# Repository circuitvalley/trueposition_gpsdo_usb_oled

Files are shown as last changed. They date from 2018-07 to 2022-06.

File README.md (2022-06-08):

PIC18F25K50 TruePosition GPSDO , USB serial, OLED.
===
/*******************************************************************************
    
    Author:  Gaurav Singh
    
    website: www.circuitvalley.com 
    
    Created on July 12, 2018
    
    PIC18F25K50 TruePosition GPSDO Controller Firmware with USB and OLED Display.

    PIC18F25K50 TruePosition GPSDO Controller Firmware with USB and OLED Display is free software: 
    you can redistribute it and/or modify it under the terms of the GNU General Public License as published by
    the Free Software Foundation, either version 3 of the License, or (at your option) any later version.

    PIC18F25K50 TruePosition GPSDO Controller Firmware with USB and OLED Display is distributed in 
    the hope that it will be useful, but WITHOUT ANY WARRANTY; 
    without even the implied warranty of MERCHANTABILITY or FITNESS FOR A PARTICULAR PURPOSE.  
    See the GNU General Public License for more details.

    You should have received a copy of the GNU General Public License
    along with PIC18F25K50 TruePosition GPSDO Controller Firmware with USB and OLED Display. 
    If not, see <http://www.gnu.org/licenses/>.

*******************************************************************************/
#Distribution Board Blog post
https://www.circuitvalley.com/2018/07/diy-isolated-10mhz-distribution-amp-gpsdo-rubidium-tcxo-reference.html

#Trueposition GPSDO
https://www.circuitvalley.com/2018/07/gpsdo-10mhz-standard-reference-clock-distribution-trueposition-gps-tcxo-ocxo.html

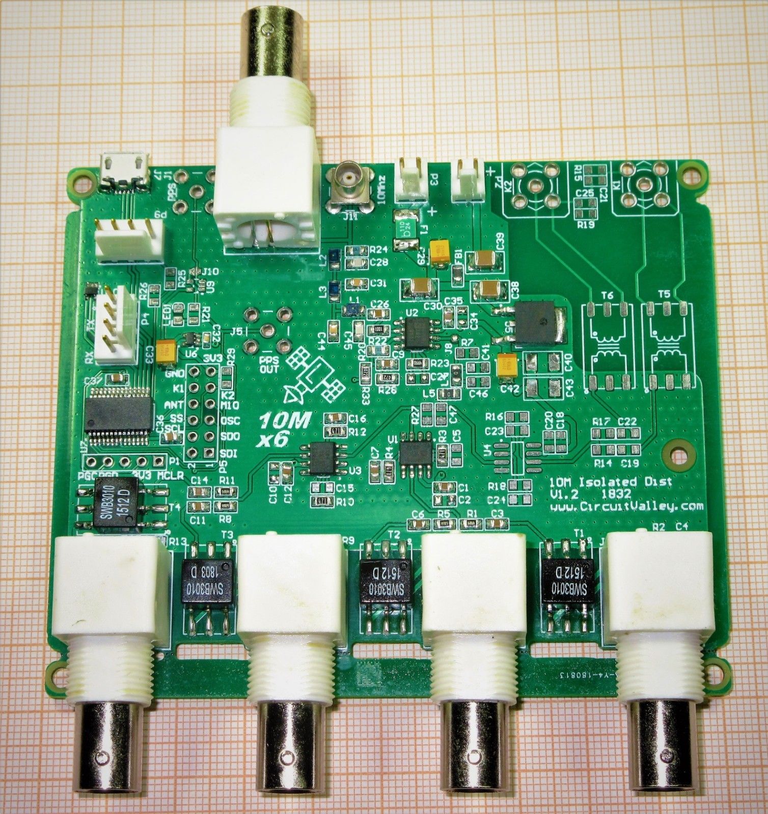
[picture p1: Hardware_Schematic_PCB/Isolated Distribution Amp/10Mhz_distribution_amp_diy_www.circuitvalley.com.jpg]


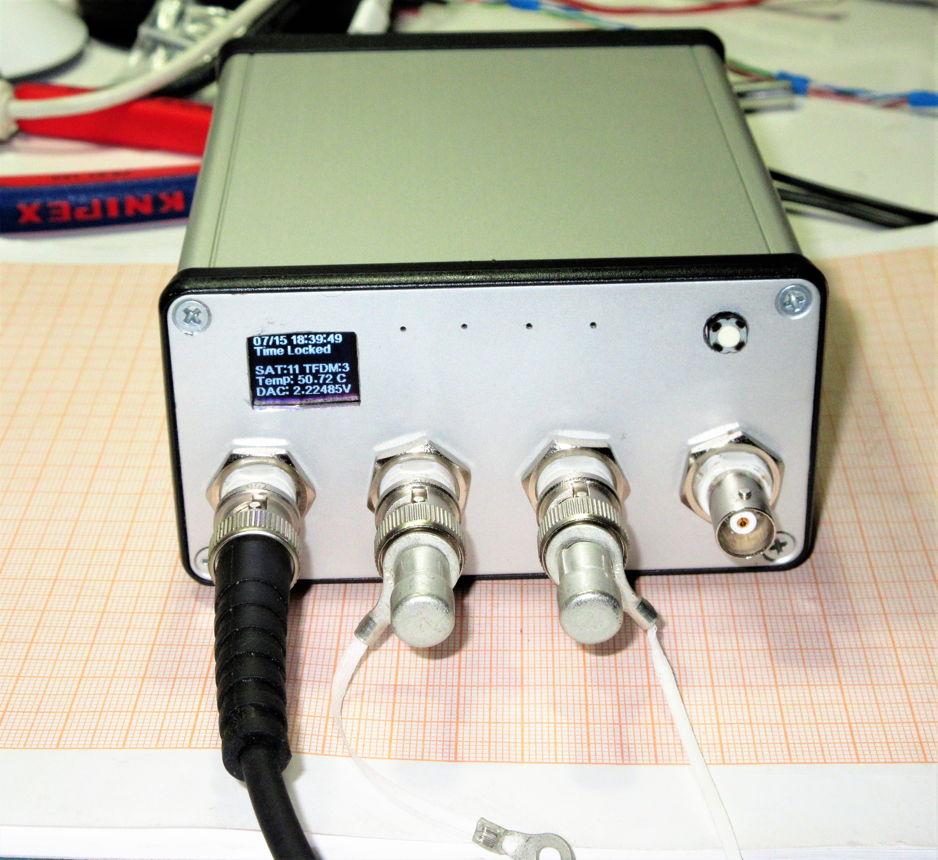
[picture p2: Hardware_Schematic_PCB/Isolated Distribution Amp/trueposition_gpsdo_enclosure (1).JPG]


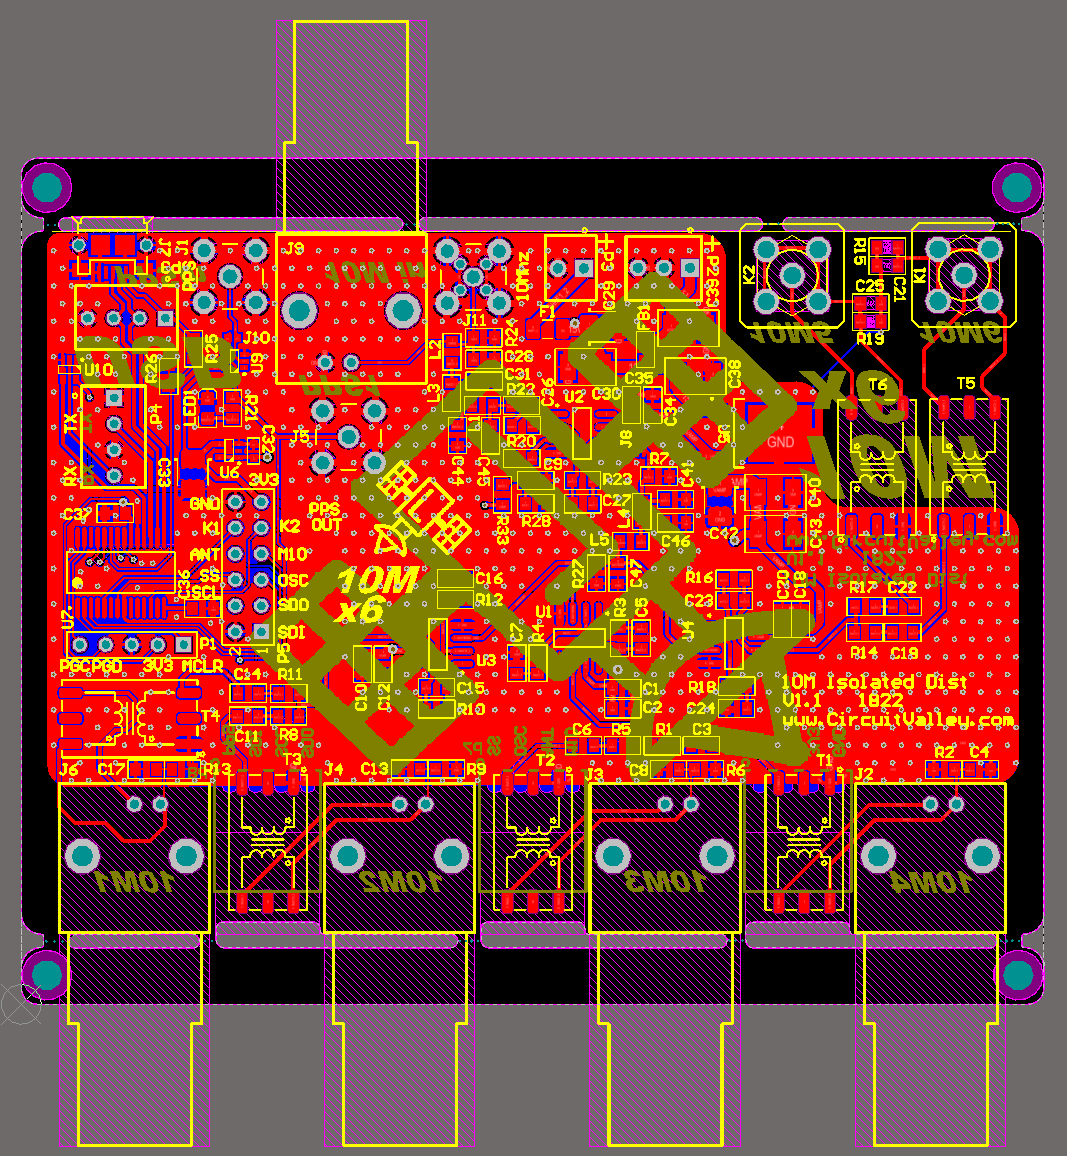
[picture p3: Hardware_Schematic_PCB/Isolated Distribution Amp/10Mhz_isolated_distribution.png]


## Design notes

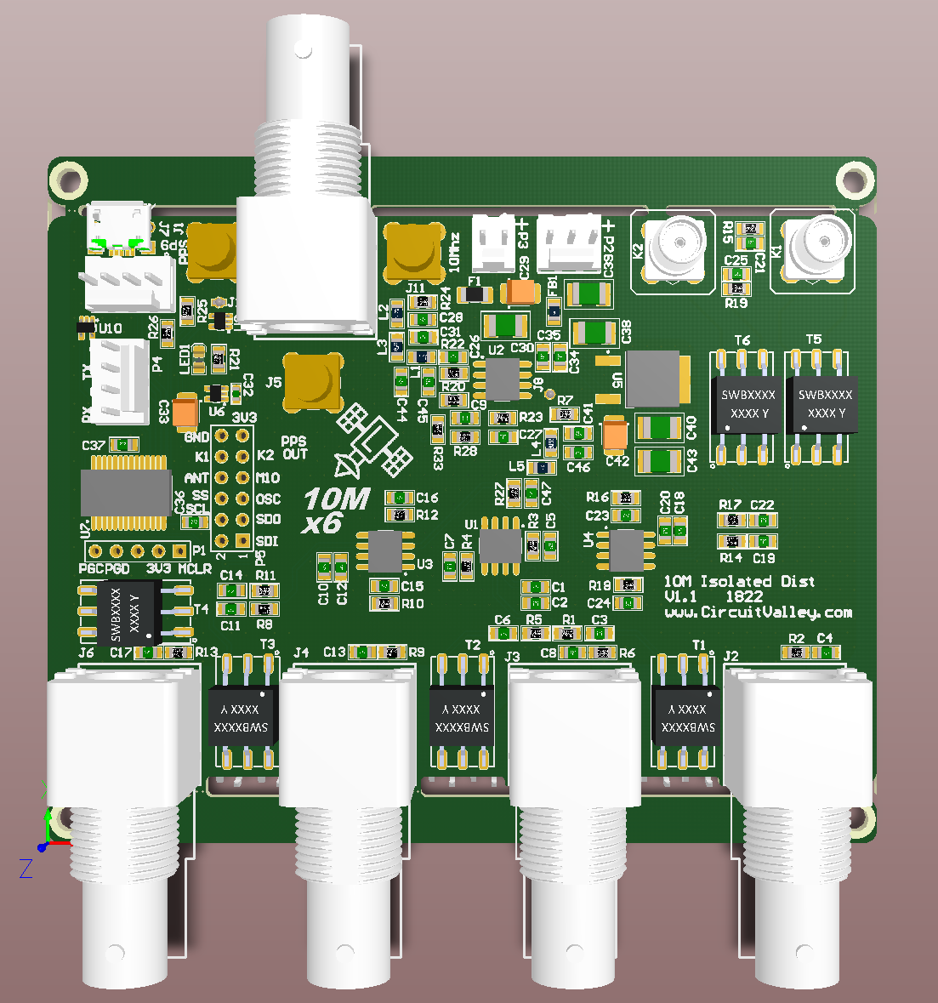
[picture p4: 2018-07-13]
Hardware_Schematic_PCB/Isolated Distribution Amp/10Mhz_isolated_distribution_3d_3.png

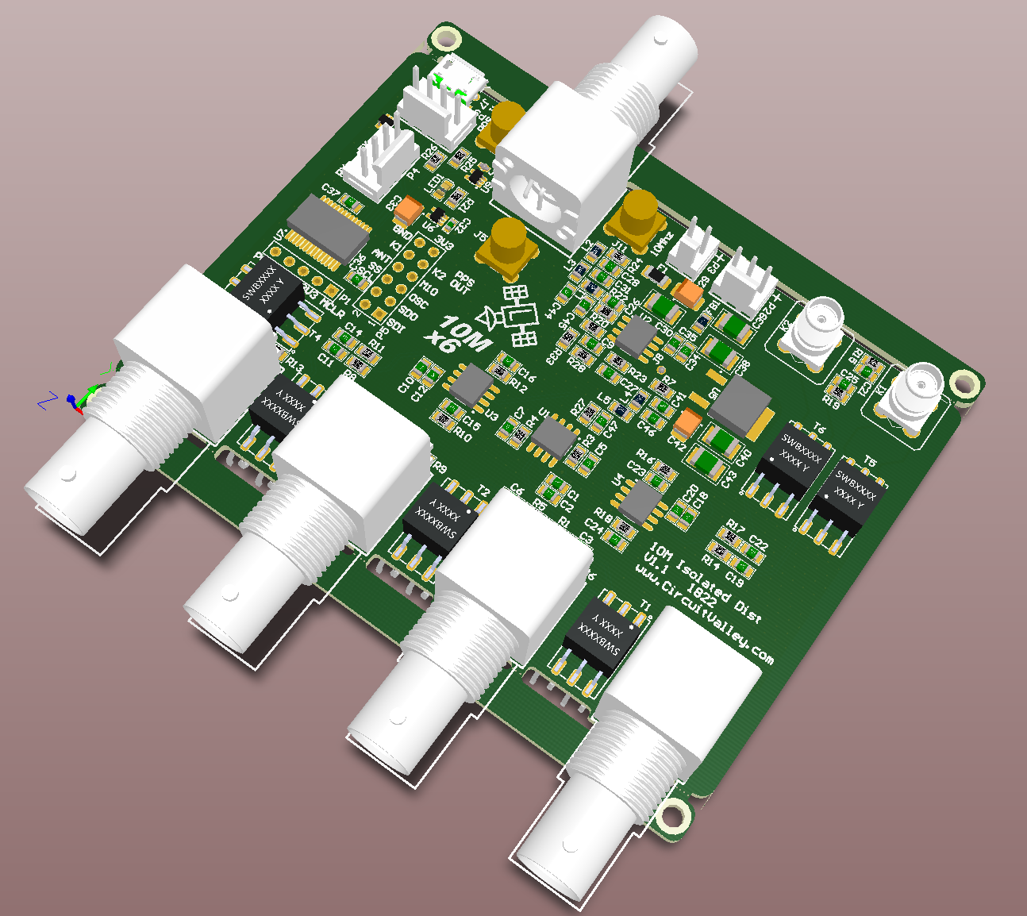
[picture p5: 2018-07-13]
Hardware_Schematic_PCB/Isolated Distribution Amp/10Mhz_isolated_distribution_3d_1.png

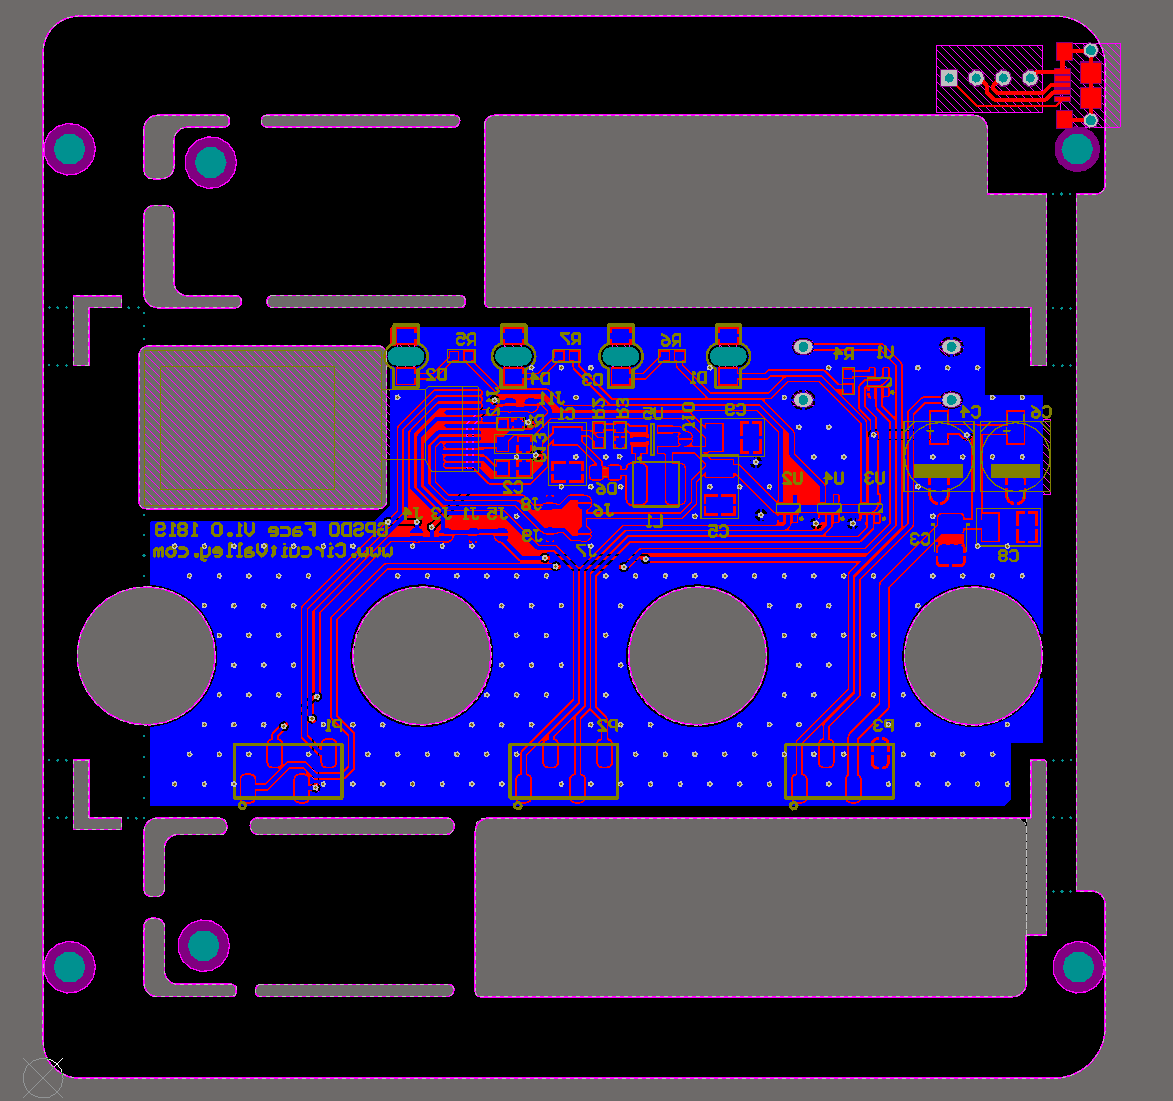
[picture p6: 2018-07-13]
Hardware_Schematic_PCB/Front Panel/Front_layout.png

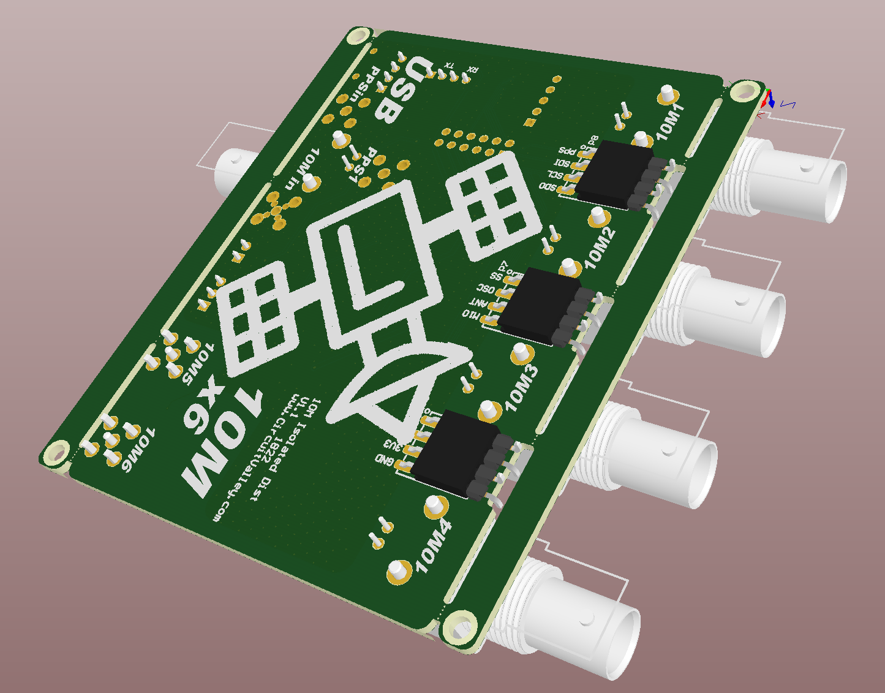
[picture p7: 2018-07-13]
Hardware_Schematic_PCB/Isolated Distribution Amp/10Mhz_isolated_distribution_3d.png

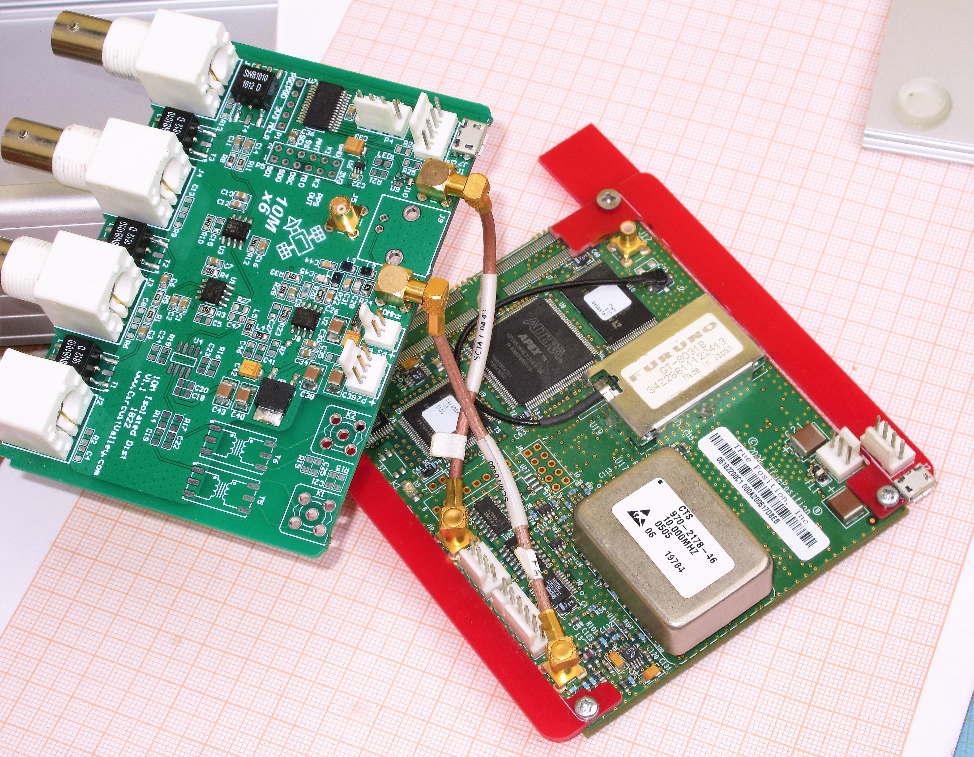
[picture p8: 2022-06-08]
Hardware_Schematic_PCB/Isolated Distribution Amp/10_Mhz_GPSDO.JPG

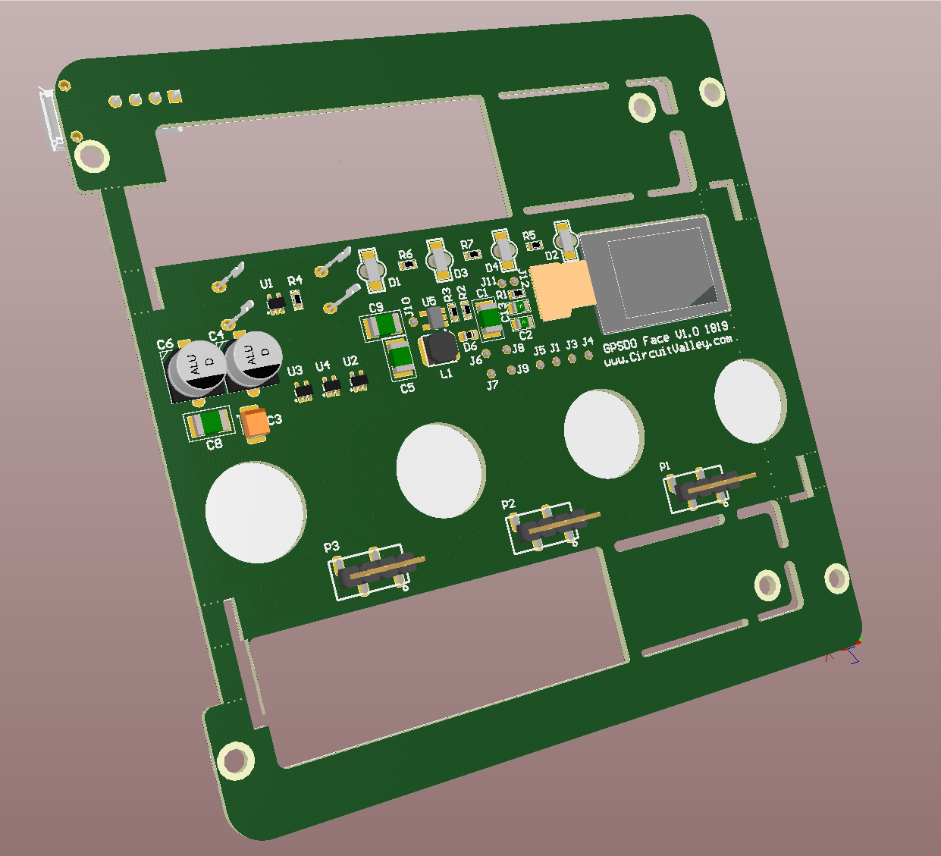
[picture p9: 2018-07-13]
Hardware_Schematic_PCB/Front Panel/Front_layout_3d.png

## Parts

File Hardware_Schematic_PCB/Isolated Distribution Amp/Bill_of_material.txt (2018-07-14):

Comment				Description							Designator																	Footprint				Quantity	Part Number
10u	Cap 			Ceramic 0805						"C1, C9, C10, C18, C34"														0805					5	GRM21BC81C106KE15L
100n				Cap Ceramic 0805					"C2, C3, C6, C7, C11, C12, C14, C16, C19, C20, C22, C24, C35, C37"			0805					14	GRM21BR71H104KA01K
NC					Cap Ceramic 0805					"C4, C5, C8, C13, C15, C17, C21, C23, C25, C27, C41, C46, C47"				0805					13	
10n					Cap Ceramic 0805					C26																			0805					1	
220p				Cap Ceramic 0805					"C28, C45"																	0805					2	CC0805FRNPO9BN221
10µ					Cap Tantalum 47uF 20% 6.3V 			"C29, C33, C42"																CAPMP3528X210N			3	
10uf				Cap Ceramic 1210					"C30, C38, C39, C40, C43"													1210					5	GRM32DC81E106KA12L
470p				Cap Ceramic 0805					"C31, C44"																	0805					2	VJ0805Y471JXAPW1BC
100n				Cap Ceramic 0603					C32																			0603					1	C0603X104K5RAC
470n				Cap Ceramic 0805					C36																			0805					1	CL21B474KBFNFNE
MOUNT 2.7x6.2Mask	Mouting hole						"DRL1, DRL2, DRL3, DRL4"													2m75_6m2				4	
0ZCG0110BF2B		Fuse 2A PTC							F1																			RESC3216N				1	0ZCG0110BF2B
ILHB0805ER300V		FERRITE BEAD 600 OHM 2A				FB1																			0805					1	ILHB0805ER300V
MCX					"MCX Female Connector, Thru-Hole"	J1																			CON-MCX					1	919-382J-51P
BNC					BNC Connector Right Angle			"J2, J3, J4, J6, J9"														1-1634612-0				5	1-1337543-0 / 1-1634612-0
MCX					RP-MCX Female PCB Mount Connector	"J5, J11"																	CON-REVMCX				2	919-382J-51P
Micro-USB-B			Micro USB Connector					J7																			10118193-0001lfc		1	10118193-0001lfc
Solder Jumper		Solder Jumper						J8																			BYPASS-MINI-CLOSED		1	
Solder Jumper		Solder Jumper						J10																			BYPASS-CLOSED			1	
SMA-V				SMA THREADED CONNECTOR 				"K1, K2"																	SMA-V					2	NC
1u					Inductor							"L1, L2"																	0805					2	0805LS-102XGEB
1.2u				Inductor							L3																			0805					1	0805LS-122XGEB
0R					Inductor							"L4, L5"																	0805					2	RC0805FR-070RL
NC					"LED, 0805 SMD, Green"				LED1																		0805					1	
Header 5			"Header, 5-Pin ICSP"				P1																			HDR1X5					1	
22-23-2031			Molex connector 3 Pin				P2																			22-23-2031				1	22-23-2031
22-23-2021			Molex connector 2 Pin				P3																			22-23-2021				1	22-23-2021
22-23-2041			Molex connector 4 Pin				"P4, P9"																	22-23-2041				2	22-23-2041
Header 6X2			"Header, 6-Pin, Dual row"			P5																			HDR2X6					1	
M20-7910442R		SMD Female Header					"P6, P7, P8"																M20-7910442R			3	M20-7910442R
49R9				    Resistor 0805						"R1, R5, R8, R11, R14, R17"													0805					6	NRC10F49R9TRF
NC					Resistor 0805						"R2, R6, R7, R9, R13, R15, R19, R21, R27"									0805					9	
470R				Resistor 0805						"R3, R4, R10, R12, R16, R18"												0805					6	RR1220P-471-D
150R				Resistor 0805						"R20, R24"																	0805					2	RK73H2ATTDD1500F
1K					Resistor 0805						R22																			0805					1	RC0805FR-131KL
499R				Resistor 0805						R23																			0805					1	RC0805FR-07499RL
75K					Resistor 0805						R25																			0805					1	RR1220P-753-D
100K				Resistor 0805						R26																			0805					1	CRCW0805100KFKEA
4.7K				Resistor 0805						"R28, R33"																	0805					2	ERA6AEB472V
SWBxxxx				RF Transformer						"T1, T2, T3, T4, T5, T6"													SWBxxxx					6	SWB1010
AD8009ARZ			"Very High Speed, Opamp"			"U1, U2, U3, U4"															SOIC8					4	AD8009ARZ
TL750M10CKVURG3		"LDO, 750 mA, 10 V Output,max 26V"	U5																			TI-KVU3_N				1	TL750M10CKVURG3
MIC5213-3.3YC5		LDO 3.3V							U6																			SC70-5					1	MIC5213-3.3YC5
PIC18F25K50-I/SS	"Microcontroller  48 MHz USB"		U7																			MCHP-SSOP-SS28_N		1	PIC18F25K50-I/SS
NC					Logic Buffer						U9																			SC70-5					1	74LVC1G17GW-Q100
74LVC1G17GW			Logic Buffer						U10																			SC70-5					1	74LVC1G17GW-Q100

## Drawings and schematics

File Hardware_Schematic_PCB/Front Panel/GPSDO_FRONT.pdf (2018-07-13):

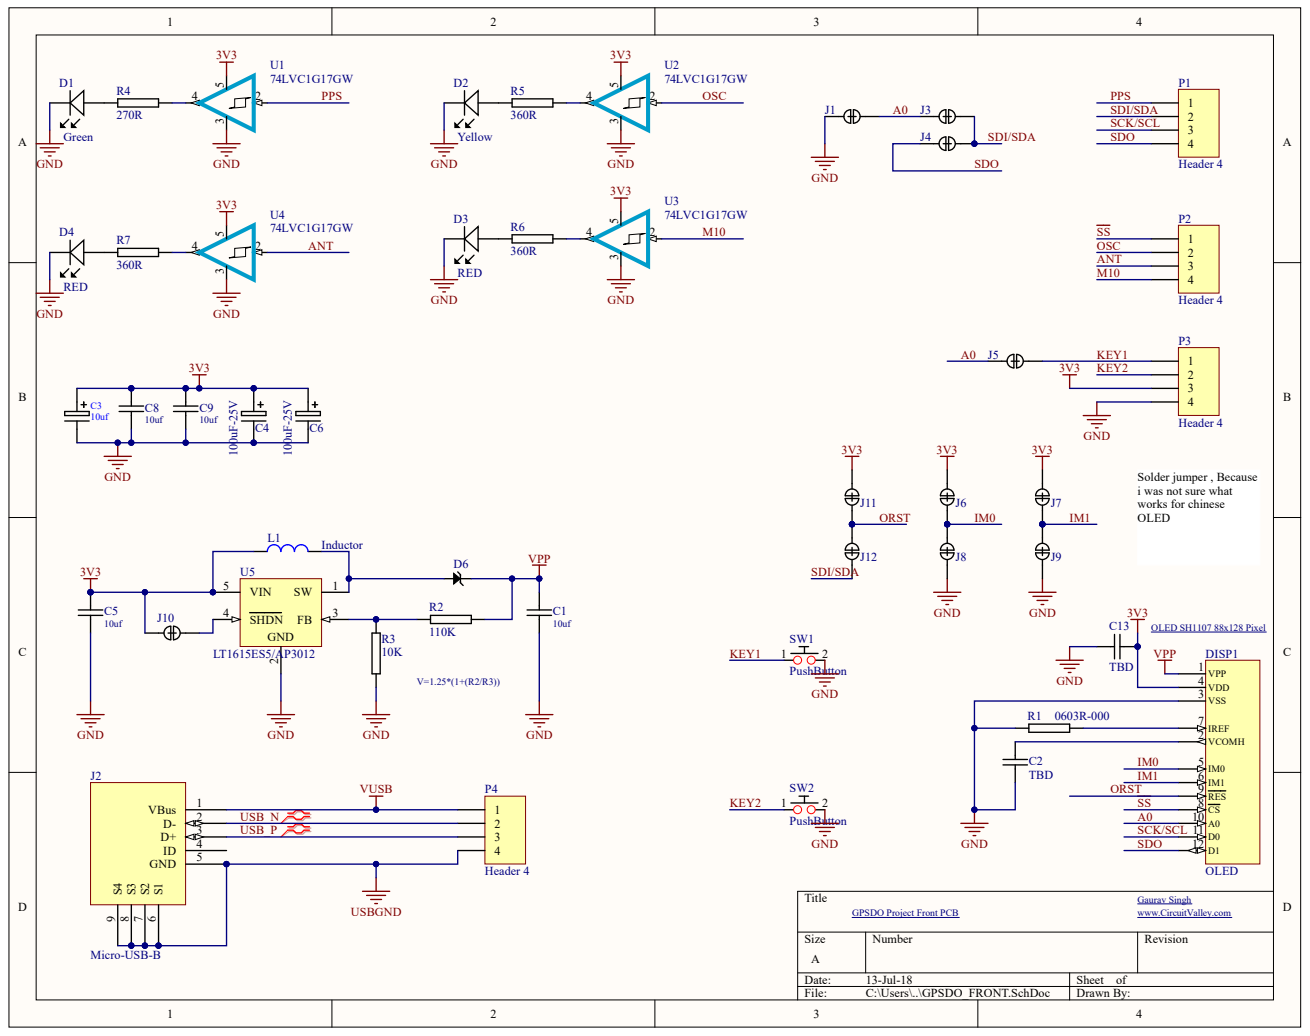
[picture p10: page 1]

Solder jumper , Because
i was not sure what
works for chinese
OLED

R1 0603R-000 | IREF 7

VCOMH 2

GPSDO Project Front PCB

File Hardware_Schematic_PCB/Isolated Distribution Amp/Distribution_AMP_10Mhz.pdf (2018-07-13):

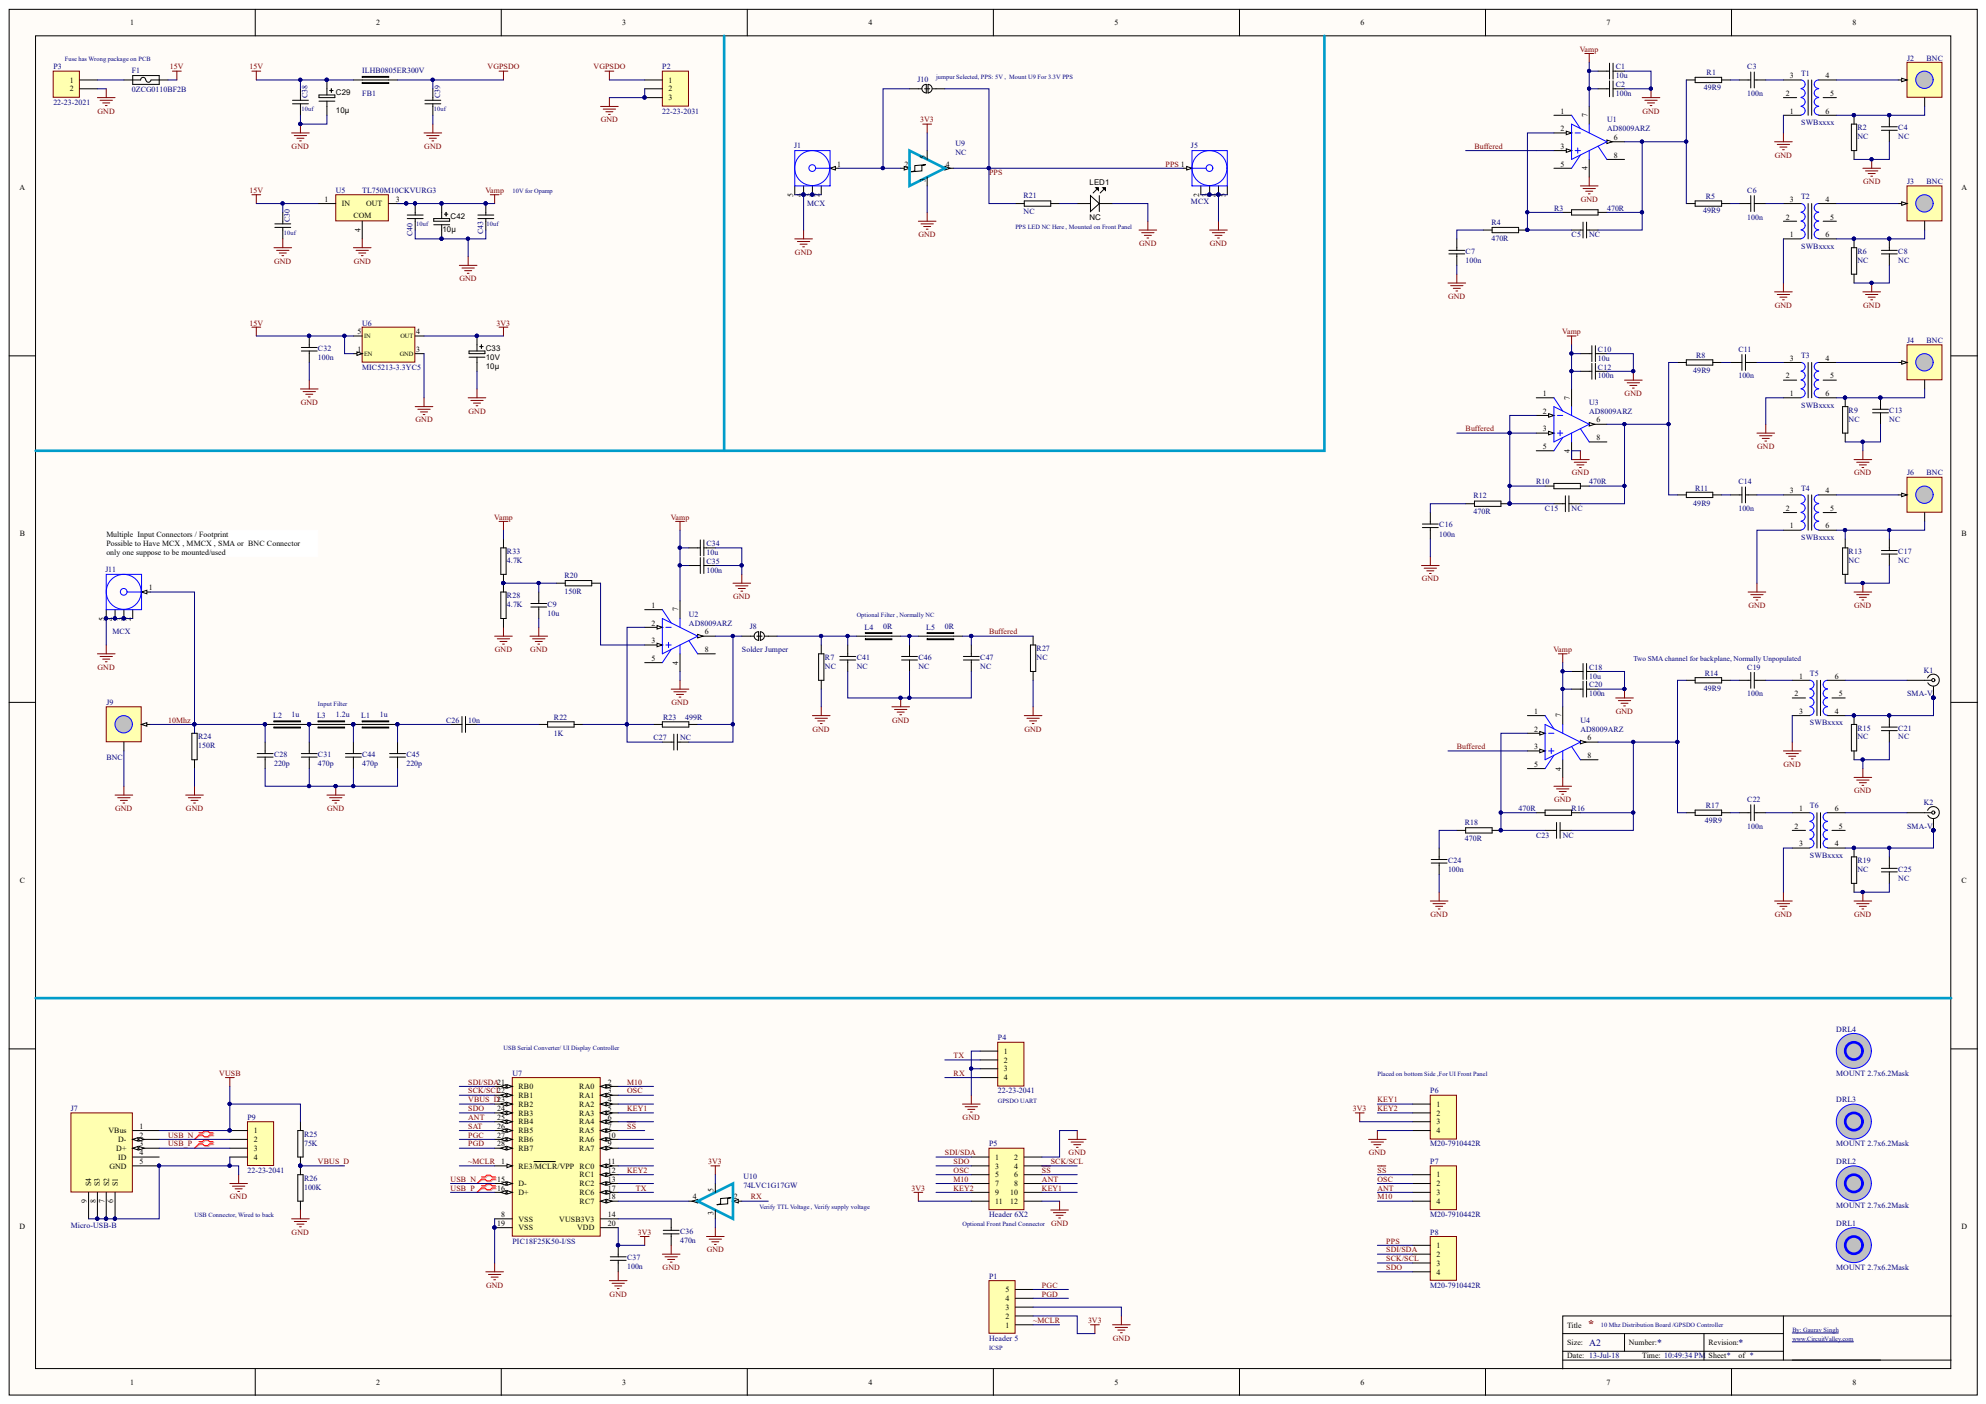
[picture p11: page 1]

Fuse has Wrong package on PCB P3 15V 15V VGPSDO VGPSDO P2 10V for Opamp | J10 jumpur Selected, PPS: 5V , Mount U9 For 3.3V PPS

PPS LED NC Here , Mounted on Front Panel

Multiple Input Connectors / Footprint
Possible to Have MCX , MMCX , SMA or BNC Connector
only one suppose to be mounted/used

Optional Filter , Normally NC

Two SMA channel for backplane, Normally Unpopulated

USB Serial Converter/ UI Display Controller

Placed on bottom Side ,For UI Front Panel

USB Connector, Wired to back

Optional Front Panel Connector

* Title 10 Mhz Distribution Board /GPSDO Controller | By: Gaurav Singh

Size: A2 | Number: * | Revision: * | www.CircuitValley.com

Date: 13-Jul-18 Time: 10:49:34 PM | Sheet * of *

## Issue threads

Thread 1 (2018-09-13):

Collaboration Request Between Two Similar Projects

KC5CQW, 2018-09-13:
I would like to broker a collaboration between two TruePosition GPSDO projects. The end goal being a more full featured controller program that spans a few of the common MCU platforms.

https://github.com/pigrew/trueposctrl
And
https://github.com/circuitvalley/trueposition_gpsdo_usb_oled/

Both projects are very similar in basic function and each to a different MCU platform. There are a few different features between them that would benefit from a merger of codes.

Closed 2023-05-23.

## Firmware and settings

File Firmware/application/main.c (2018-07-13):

/*******************************************************************************
    Author:  Gaurav Singh
    website: www.circuitvalley.com 
    Created on July 12, 2018
    
    This file is part of Circuitvalley TruePosition GPSDO Controller with OLED.
    Circuitvalley TruePosition GPSDO Controller with OLED is free software: you can redistribute it and/or modify
    it under the terms of the GNU General Public License as published by
    the Free Software Foundation, either version 3 of the License, or
    (at your option) any later version.
    Circuitvalley TruePosition GPSDO Controller with OLED is distributed in the hope that it will be useful,
    but WITHOUT ANY WARRANTY; without even the implied warranty of
    MERCHANTABILITY or FITNESS FOR A PARTICULAR PURPOSE.  See the
    GNU General Public License for more details.
    You should have received a copy of the GNU General Public License
    along with Circuitvalley TruePosition GPSDO Controller with OLED.  If not, see <http://www.gnu.org/licenses/>.
*******************************************************************************/

/** INCLUDES *******************************************************/
#include "system.h"

#include "app_device_cdc_to_uart.h"

#include "usb.h"
#include "usb_device.h"
#include "usb_device_cdc.h"

/********************************************************************
 * Function:        void main(void)
 *
 * PreCondition:    None
 *
 * Input:           None
 *
 * Output:          None
 *
 * Side Effects:    None
 *
 * Overview:        Main program entry point.
 *
 * Note:            None
 *******************************************************************/
MAIN_RETURN main(void)
{
    SYSTEM_Initialize(SYSTEM_STATE_USB_START);

    USBDeviceInit();
    USBDeviceAttach();
    
    while(1)
    {
        SYSTEM_Tasks();

        #if defined(USB_POLLING)
            // Interrupt or polling method.  If using polling, must call
            // this function periodically.  This function will take care
            // of processing and responding to SETUP transactions
            // (such as during the enumeration process when you first
            // plug in).  USB hosts require that USB devices should accept
            // and process SETUP packets in a timely fashion.  Therefore,
            // when using polling, this function should be called
            // regularly (such as once every 1.8ms or faster** [see
            // inline code comments in usb_device.c for explanation when
            // "or faster" applies])  In most cases, the USBDeviceTasks()
            // function does not take very long to execute (ex: <100
            // instruction cycles) before it returns.
            USBDeviceTasks();
        #endif
        APP_handle_gpsdo_uart_Task();
        APP_UI_Task();

        /* If the USB device isn't configured yet, we can't really do anything
         * else since we don't have a host to talk to.  So jump back to the
         * top of the while loop. */
         if( USBGetDeviceState() < CONFIGURED_STATE )
        {
            /* Jump back to the top of the while loop. */
            continue;
        }

        

        /* If we are currently suspended, then we need to see if we need to
         * issue a remote wakeup.  In either case, we shouldn't process any
         * keyboard commands since we aren't currently communicating to the host
         * thus just continue back to the start of the while loop. */
        if( USBIsDeviceSuspended()== true )
        {
            /* Jump back to the top of the while loop. */
            continue;
        }

        //Application specific tasks
        APP_DeviceCDCEmulatorTasks();


    }//end while
}//end main

/*******************************************************************************
 End of File
*/

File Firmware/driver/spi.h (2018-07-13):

/*******************************************************************************
    Author:  Gaurav Singh
    website: www.circuitvalley.com 
    Created on July 12, 2018
    
    This file is part of Circuitvalley TruePosition GPSDO Controller with OLED.
    Circuitvalley TruePosition GPSDO Controller with OLED is free software: you can redistribute it and/or modify
    it under the terms of the GNU General Public License as published by
    the Free Software Foundation, either version 3 of the License, or
    (at your option) any later version.
    Circuitvalley TruePosition GPSDO Controller with OLED is distributed in the hope that it will be useful,
    but WITHOUT ANY WARRANTY; without even the implied warranty of
    MERCHANTABILITY or FITNESS FOR A PARTICULAR PURPOSE.  See the
    GNU General Public License for more details.
    You should have received a copy of the GNU General Public License
    along with Circuitvalley TruePosition GPSDO Controller with OLED.  If not, see <http://www.gnu.org/licenses/>.
*******************************************************************************/

#ifndef _SPI_H
#define _SPI_H

#include <stdint.h>


#ifdef __cplusplus  // Provide C++ Compatability

    extern "C" {

#endif

// *****************************************************************************
/* SPI Modes Enumeration

  Summary:
    Specifies the SPI modes which can be used in the initialization structure
    to initialize the SPI for operation. 

  Description:
    Specifies the SPI bus modes enumeration for which an SPI channel
    can operate on. The SPI channel bus mode can be set in the
    SPI channel initialization routine parameter.
*/
 
typedef enum
{
    SPI_BUS_MODE_0 = 0x0050,    //smp = 0, ckp = 0
    SPI_BUS_MODE_1,             //smp = 1, ckp = 0
    SPI_BUS_MODE_2,             //smp = 0, ckp = 1
    SPI_BUS_MODE_3,             //smp = 1, ckp = 1
    
}SPI_BUS_MODES;

// *****************************************************************************
/* SPI Transfer Mode Enumeration

  Summary:
    Defines the Transfer Mode enumeration for SPI.

  Description:
    This defines the Transfer Mode enumeration for SPI.
*/

typedef enum {
    SPI_TRANSFER_MODE_32BIT  = 2,
    SPI_TRANSFER_MODE_16BIT = 1,
    SPI_TRANSFER_MODE_8BIT = 0
}SPI_TRANSFER_MODE;

// *****************************************************************************
/* SPI Initialization structure

  Summary:
    The structure that defines the SPI channel's operation.

  Description:
    Specifies the members which can be adjusted to allow the
    SPI to be initialized for each instance of SPI.
 */

typedef struct
{
    /*Channel for the SPI communication */
    uint16_t            channel;
#if defined (__PIC32MX)
    /*Baud rate for the SPI communication */
    uint16_t            baudRate;
    uint16_t            dummy;
#elif defined (__XC16__)
    /* Primary and Secondary prescalers control the SPI frequency */
    uint16_t            primaryPrescale;
    uint16_t            secondaryPrescale;
#elif defined (__XC8__)
    uint16_t            baudRate;
    uint8_t             divider;
#endif
    /* Clock Edge Selection Bits */
    uint8_t            cke;
    /* One of SPI Bus mode as specified SPI_BUS_MODES */
    SPI_BUS_MODES       spibus_mode;
    /* Select between 8 and 16 bit communication */
    SPI_TRANSFER_MODE   mode;
	
} DRV_SPI_INIT_DATA;

/* macros that defines the SPI signal polarities */
    #define SPI_CKE_IDLE_ACT     0        // data change is on active clock to idle clock state
    #define SPI_CKE_ACT_IDLE     1        // data change is on idle clock to active clock state

    #define SPI_CKP_ACT_HIGH     0        // clock active state is high level
    #define SPI_CKP_ACT_LOW      1        // clock active state is low level

    #define SPI_SMP_PHASE_MID    0        // master mode data sampled at middle of data output time 
    #define SPI_SMP_PHASE_END    1        // master mode data sampled at end of data output time

    #define SPI_MST_MODE_ENABLE  1        // SPI master mode enabled
    #define SPI_MST_MODE_DISABLE 0        // SPI master mode disabled, use SPI in slave mode

    #define SPI_MODULE_ENABLE    1        // Enable SPI 
    #define SPI_MODULE_DISABLE   0        // Disable SPI 

// *****************************************************************************
/* Function:
    void DRV_SPI_Initialize(DRV_SPI_INIT_DATA *pData)

  Summary:
    Initializes the SPI instance specified by the channel of the initialization
    structure.

  Description:
    This routine initializes the spi driver instance specified by the channel
    of the initialization structure making it ready for clients to lock and
    use it.

  Precondition:
    None.

  Returns:
    None.

  Parameters:
    pData      - SPI initialization structure.

  Example:
    <code>
    uint16_t           myBuffer[MY_BUFFER_SIZE];
    unsigned int       total;
    uint8_t            myChannel = 2;
    DRV_SPI_INIT_DATA  spiInitData = {2, 3, 7, 0, SPI_BUS_MODE_3, 0};

    DRV_SPI_Initialize(&spiInitData);
    DRV_SPI_Lock(myChannel);

    total = 0;
    do
    {
        total  += DRV_SPI_PutBuffer( myChannel, &myBuffer[total], MY_BUFFER_SIZE - total );

        // Do something else...

    } while( total < MY_BUFFER_SIZE );

    </code>

  Remarks:
    This routine must be called before any other SPI routine is called.
    This routine should only be called once during system initialization.
    Current implementation supports 8-bit transfer mode only.
*/

void DRV_SPI_Initialize(DRV_SPI_INIT_DATA *pData);

// *****************************************************************************
/* Function:
    void DRV_SPI_Deinitialize (uint8_t channel)

  Summary:
    Deinitializes the SPI instance specified by the channel parameter

  Description:
    This routine deinitializes the spi driver instance specified by the channel
    parameter.

  Precondition:
    None.

  Returns:
    None.

  Parameters:
    channel      - SPI instance which needs to be deinitialized.

  Example:
    <code>
    uint8_t            myChannel = 2;

    DRV_SPI_Deinitialize(myChannel);
    </code>

  Remarks:
    None.
*/

void DRV_SPI_Deinitialize (uint8_t channel);
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

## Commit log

2018-07-13 microchip driver files added
2018-07-13 Hardware Schematic and PCB Source
    [Distribution_amp_10Mhz.SchDoc]
2018-07-13 Hardware Files added
    [Distribution_amp_10Mhz.SchDoc, GPSDO_FRONT.SchDoc, GPSDO_FRONT_PCB.PcbDoc]
2018-07-14 Added excel Bill_of_material.xlsx
    [Bill_of_material.xlsx]
2019-01-16 Gerber files added
2022-06-08 Added Board and GPSDO Images
